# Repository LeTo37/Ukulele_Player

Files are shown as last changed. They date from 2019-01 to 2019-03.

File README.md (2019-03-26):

# Human-Robot Ukulele Player (H-RUP)
Designing and building a Human-Interactable Robotic Ukulele player. Below is a link to video of me playing the H-RUP!

Sawyer Ukulele Tune (https://www.youtube-nocookie.com/embed/SKRP2N837I4 "HRUP")

## Introduction
This repository holds all of the relevant documentation, including mechanical designs, circuit designs, code and data-sheets of the parts used in the process of designing and building the Human-Robot Ukulele Player (H-RUP). 

This project was done in fulfillment of the requirements of a winter quarter project for the completion of my Master of Science in Robotics at Northwestern University.

## Approach

The basic approach I followed was to develop a 4x4 bank of solenoids to be housed above a small section of the ukkulele neck, placed above a part of the ukulele whereby this bank of solenoids will be able to press a pretty comprehensive combination of notes/chords, enough to be able to play most, if not all songs.

These solenoids are controlled using a PIC32MX795F512H microcontroller and a driver circuit. The Ukulele and Solenoid housing were designed and constructed by 3D printing and Laser Cutting. Coding was done C and Python.

## Directories

### Mechanical Designs

This directory holds the mechanical designs used to construct the H-RUP. Designs were done in Onshape, an open source, online CAD tool.

### Circuit Schematics

This directory holds the circuit design schematics for the solenoid drivers. Designs wer done in kiCad, an open source, PCB and schematics design tool.

### Docs
This directory holds the datasheets for all the relevant components used and any other useful documentation.

### Code
This directory holds the code used to program the PIC32MX795F512H microcontroller on the [NU32](http://hades.mech.northwestern.edu/index.php/NU32) breakout board. It also holds the user code used to run and interact with the H-RUP

## Using the H-RUP
[Ukulele Jukebox](Code/user_code/Ukulele_Jukebox.py) is a Python executable that will initiate the user interface for the H-RUP. First the user will be welcomed and prompted for a choice of entering their own song or choosing from a list of preset songs on the Jukebox.

If a user wants to create their own song, they will be asked for each individual chord and the amount of milliseconds they wish for that chord to be played. The user can end a song by entering a '%' when asked for a chord.

If a user wants to choose a song, they will be given a list of songs from which to choose.

In both cases, once a song has either been written or chosen, the list of chords and milliseconds will be sent to the microcontroller. At this point the strum light will count down from 3 with 3 long flashes. It will then flash quickly each time a chord is played to indicate that a strumming sequence should begin!

Happy Strumming!

<p align="center">
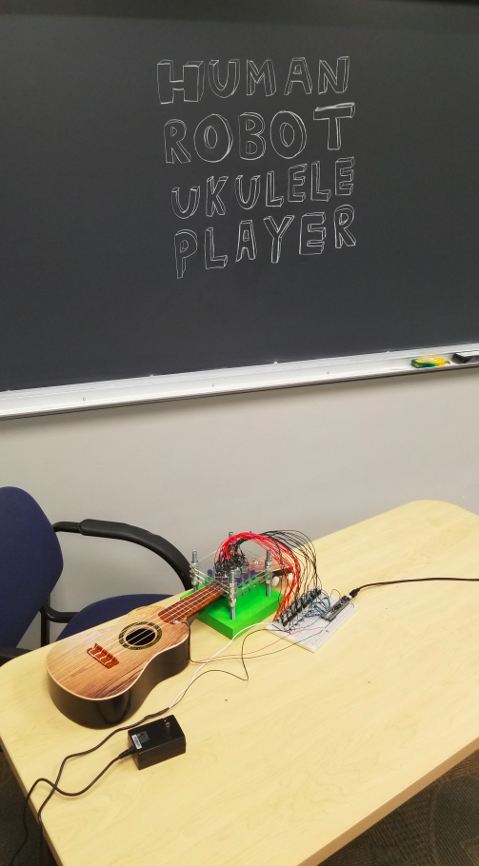
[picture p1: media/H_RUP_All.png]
  
</p>

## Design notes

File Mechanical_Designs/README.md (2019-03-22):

# Mechanical Designs

## Final Full Assembly

This final design was implemented with a combination of 3d printing PLA parts and Laser cutting Acryllic parts. The Full Assembly can be found [here](Full_Assembly.stl). The fully constructed mechanism is shown in the image below:
<p align="center">
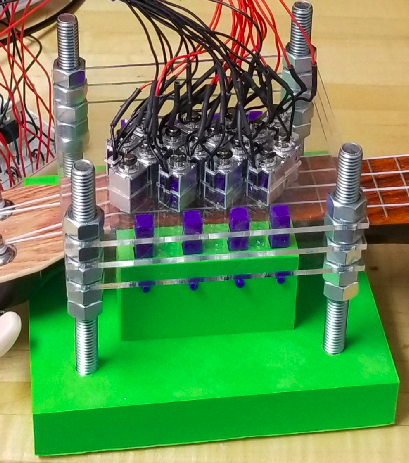
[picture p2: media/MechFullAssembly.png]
  
</p>
As can be seen, it is comprised of a few different components which are described below.

## 3D Printables

The design of the [Base and Ukulele Housing](3D_Prints/Base_and_Uke_Housing.stl) was 3d printed out of PLA plastic. This serves as the base of the design and is where the neck of the Ukulele rests. It is made out of a [base](3D_Prints/base.stl) and a [housing](3D_Prints/Housing_Base.stl) for the Ukulele. It was designed such that the Ukulele can rest with it's first four frets accessable to the solenoids. This is a big chunk of plastic and was designed as such, so as to provide overall stability to the system.

Further parts that were 3D printed include the [Housing Aligners](3D_Prints/Housing_Aligners.stl), the [Pins](3D_Prints/Pin.stl) and the [Fingertips](3D_Prints/Fingertips.stl). The Housing Aligners are used to connect the 3D printed Base and Ukulele Housing to the laser cut parts that house the solenoids described below. This is done as a way of ensuring the parts line up such that the solenoids are above the correct part of the Ukulele neck. The Pins are used simply to connect the Housing Aligners to the Base and Ukulele Housing to improve stability.

The Fingertips were printed out of NinjaFlex 3D printer filament. This was done as it produces a much more flexibale part. These fingertips were connected to the end of the solenoid plunger, as an end-effector to press chords on the Ukulele.

## Laser Cuttables

In order to both house and align the solenoids such that they are able to press the correct chords, the solution was designed to be done in three layers. This decision was made in order to allow for as much air flow through the system as possible - necessary since the solenoids are being driven over voltage. Each layer was drawn and saved in '.svg' format, these drawings were then cut out of Acryllic using a laser cutter.

As such, the [bottom layer](Laser_Cuts/bottom_solenoid_holder.svg) was drawn to have holes for the solenoid plunger to be able to press down on the correct part of the Ukulele neck, but these holes are only big enough for the plunger, that is to say, this layer holds the solenoids from the bottom. It also includes square holes for the 3D printed Housing Aligners to fit through, so as to ensure accurate alignment. The [middle layer](Laser_Cuts/middle_solenoid_holder.svg) was drawn to house the solenoids and ensure their alignment is such that their plungers go through the holes on the bottom layer. Lastly, the [top layer](Laser_Cuts/top_solenoid_holder.svg), similarly to the bottom layer, has holes large enough only for the solenoid plungers and secondary holes for the solenoid wiring. This layer serves to compress the solenoids so that when they are activated, all of their force goes into pressing the plunger down onto the Ukulele.

## Other Parts
The [Solenoid](Other_Parts/Solenoid.stl) and [Ukulele Neck](Other_Parts/Ukulele.stl) designs were used within the CAD design of all of the necessary parts that make the final full assembly. They were made to be the same size as the real part such that the designed parts were accurate and reliable.

Threadbars and appropriately sized nuts were ordered from McMaster-Carr to be used in the real life assembly of the design. In CAD, this [Threadbar](Other_Parts/Threadbar.stl) was used as a placeholder for the final full assembly design. The parts ordered and used were:
* Low-Strength Steel Hex Nut, Grade 2, Zinc-Plated, 3/8"-16 Thread Size
* Low-Strength Zinc-Plated Steel Hex Head Screw, 3/8"-16 Thread Size, 5" Long, Fully Threaded

The threadbar and nut combination was used to both compress and space the three laser cut-out layers that house the solenoids.

## Unused Designs
This folder holds some of the unused designs that were iterated through in the process of getting to the final design shown in the root of this directory.

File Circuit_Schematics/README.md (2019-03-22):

# Circuit Schematics

The schematics in this directory called [Solenoid Drivers 1](Solenoid_Drivers_1.png) and [2](Solenoid_Drivers_2.png) are mostly the same. Between the two of them they describe 16 solenoid driver circuits designed to allow Digital I/O pins on the PIC32 microcontroller to activate and deactivate the solenoids with logic highs and lows. The only differnece between Solenoid Drivers 1 and 2 are the Digital I/O pins to which the solenoid driver circuit is connected.

The basic circuit that is repeated for all 16 solenoids consists of the Digital I/O pin going through a 1 kilo Ohm resistor to the base of an NPN Darlington transistor. The collector of which is connected to a 7.5V power supply (32W, 4.32A AC/DC wall adapter) through a parallel combination of the solenoid being activated and a flyback diode. The emmitter of the transistor is connected to ground. The datasheets for the components used can be found [here](../Docs)

The [LED](LED.png) schematic shows a simple connection from the PIC32 Digital I/O to an LED with a 330 Ohm pulldown resistor. This LED is used as the Start and Strum Light to indicate to the user when to strum.

These schematics were developed using KiCad, as such, the KiCad '.sch' files are included as well as screenshots of the schematics for easier viewing.

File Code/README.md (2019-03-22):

# Code

This repository holds all of the code necessary to use the H-RUP. 

## Microcontroller Code
This directory holds the code used to program the PIC32MX795F512H microcontroller. The purpose of this code is to read a song sent into the microcontroller by the user code and convert that into digital highs or lows such that the solenoids actuate at the correct time. This allows the H-RUP to press chords on the Ukulele in the correct sequence and timing, producing a song.

The PIC32MX795F512H code is all done in C for use with the NU32 breakout board.

## User Code
This directory holds code that defines how the user interacts with H-RUP. Included in this directory is a Python script called [Ukulele Jukebox](/Ukulele_Jukebox.py) as well as text files holding the chords and timing instructions for a few preset songs.

The protocol Ukelele Jukebox uses for reading songs is defined as `chord,milliseconds,chord,milliseconds,..`. That is to say the code reads a chord and then the amount of milliseconds that chords should be played for seperated by a comma. The list of chords and milliseconds ends when there are no more commas.

Ukulele Jukebox is an executable that will initiate the user interface for the H-RUP. First the user will be welcomed and prompted for a choice of entering their own song or choosing from a list of preset songs on the Jukebox.

If a user wants to create their own song, they will be asked for each individual chord and the amount of milliseconds they wish for that chord to be played. The user can end a song by entering a '%' when asked for a chord.

If a user wants to choose a song, they will be given a list of songs from which to choose.

In both cases, once a song has either been written or chosen, the list of chords and milliseconds will be sent to the microcontroller. At this point the strum light will count down from 3 with 3 long flashes. It will then flash quickly each time a chord is played to indicate that a strumming sequence should begin!

## NU32
All of the code found in both the [micro code](/micro_code) directory and the [NU32 Utility](/NU32_Utility) that has "NU32" in its name is code developed by the makers of the [NU32](http://hades.mech.northwestern.edu/index.php/NU32) breakout board for the PIC32MX795F512H microcontroller. This code includes Utility code (in the NU32 Utility directory) which defines functions and data types for the bootloader. This bootloader is included in the micro code directory along with an NU32 library of functions that are useful for initialising the micro as well as serial communication to and from the micro.

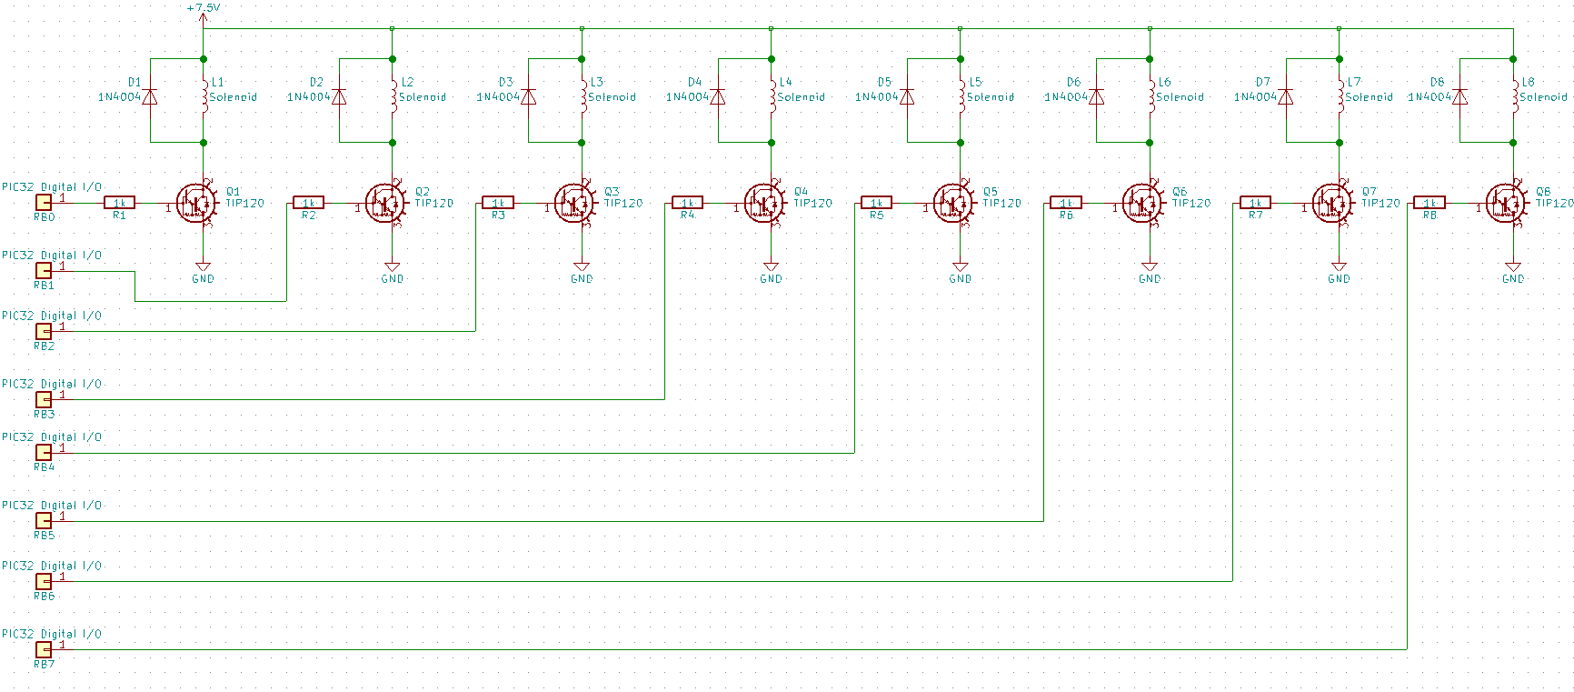
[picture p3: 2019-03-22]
Circuit_Schematics/Solenoid_Drivers_1.png

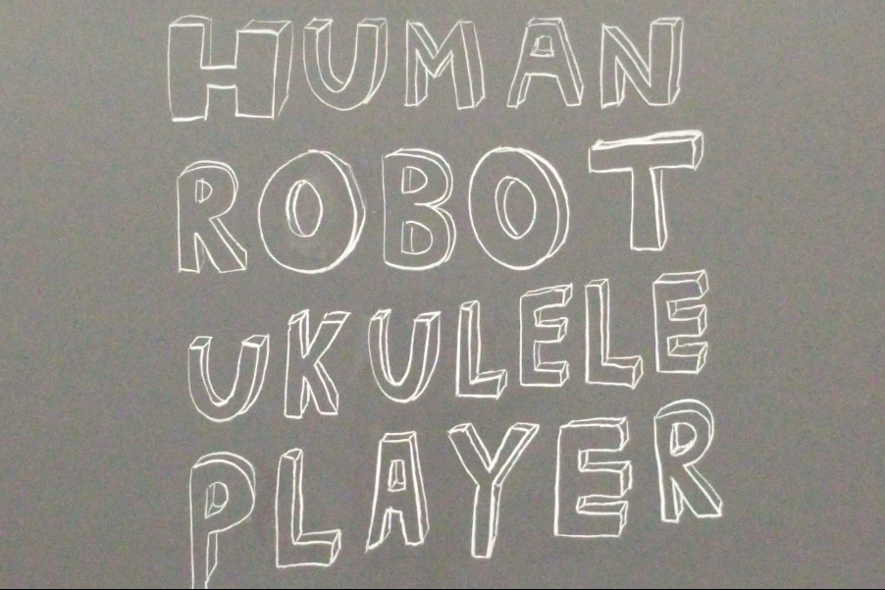
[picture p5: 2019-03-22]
media/H_RUP_Writing.png

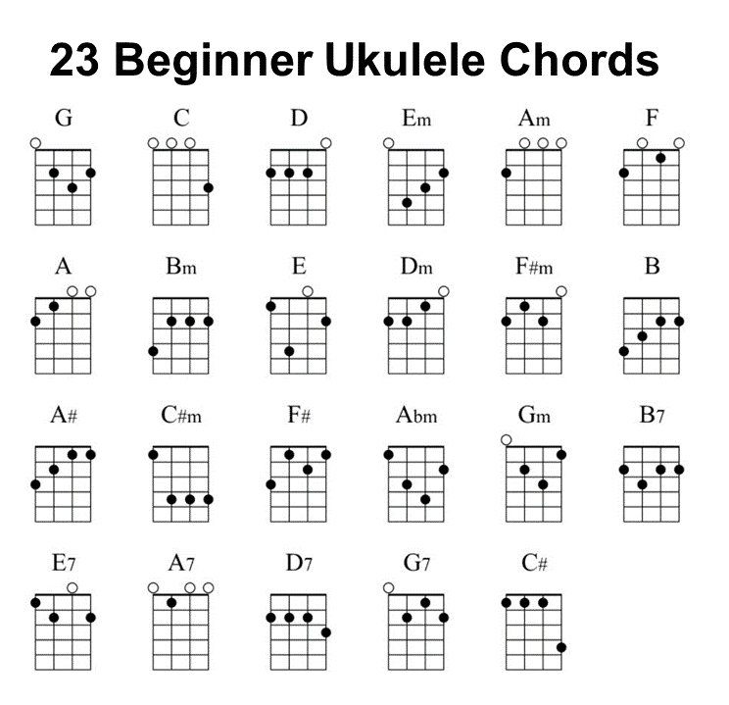
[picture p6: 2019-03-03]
Docs/Base23_Ukulele_Chords.png

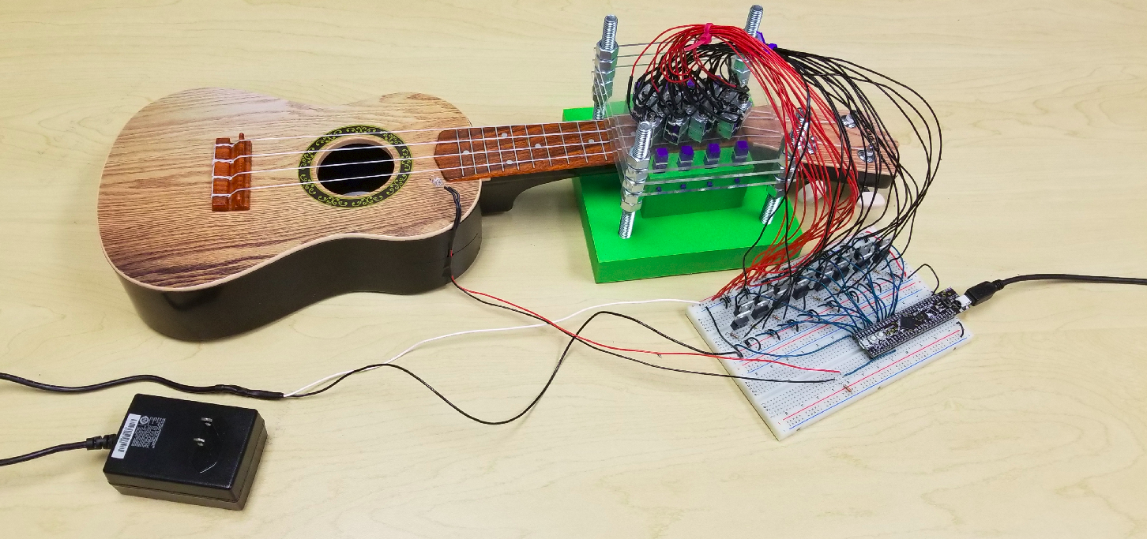
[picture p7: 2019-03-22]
media/H_RUP.png

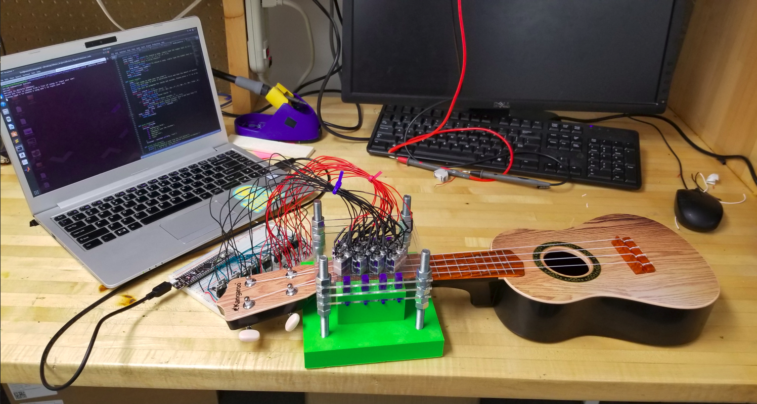
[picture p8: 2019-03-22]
media/H_RUP_Code.png

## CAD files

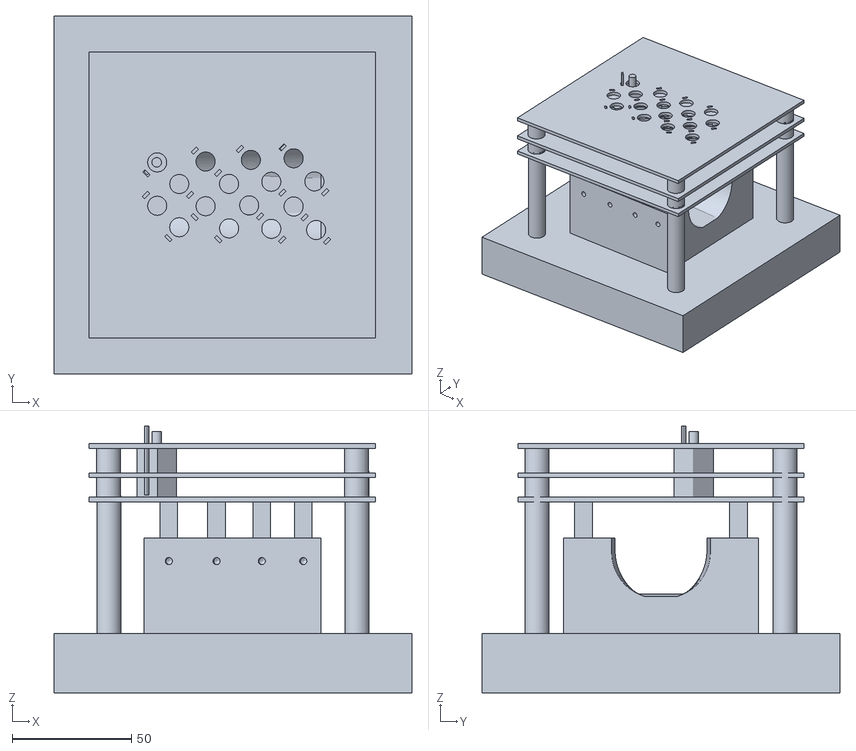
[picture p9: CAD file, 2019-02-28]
Mechanical_Designs/Full_Assembly.stl
150.0 x 150.0 x 111.8

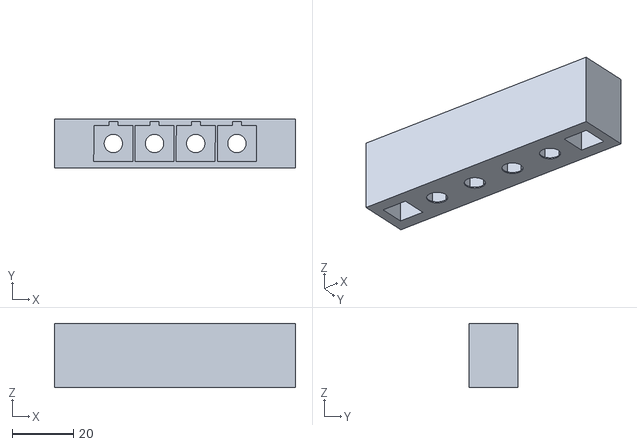
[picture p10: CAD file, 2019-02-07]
Mechanical Designs/Housing_Solenoids_2.stl
79.0 x 16.0 x 21.0

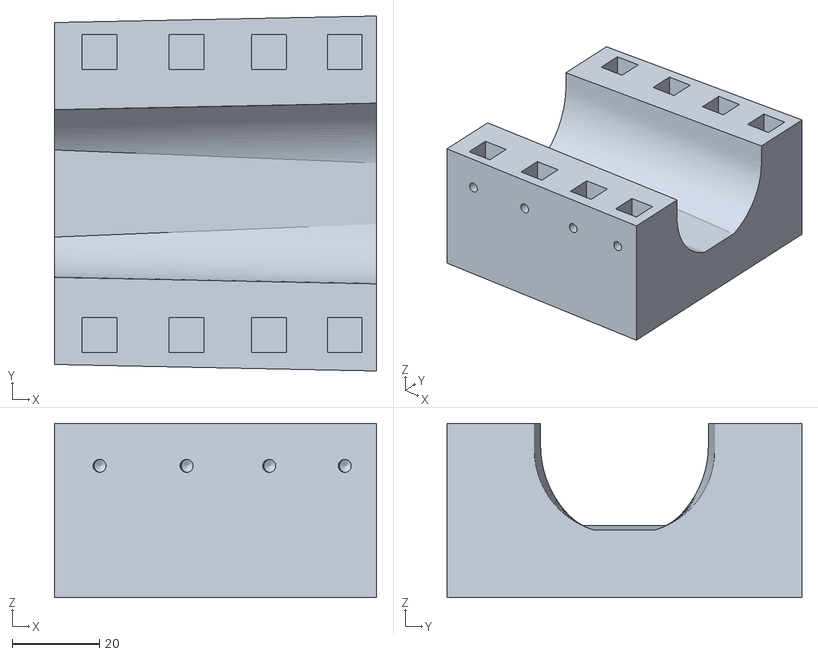
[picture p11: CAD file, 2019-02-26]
Mechanical_Designs/3D_Prints/Housing_Base.stl
74.0 x 81.5 x 40.0

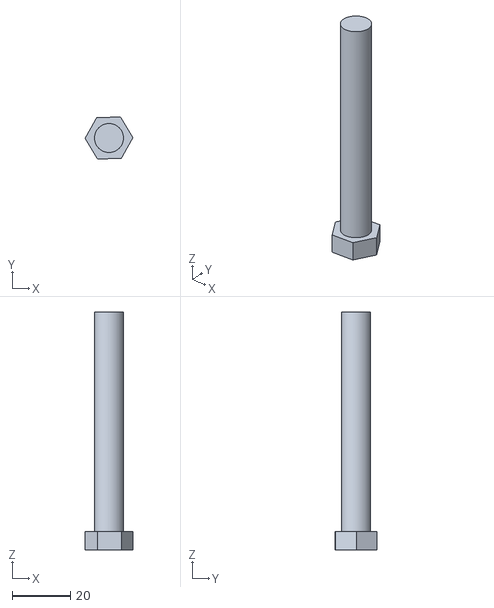
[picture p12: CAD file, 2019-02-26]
Mechanical_Designs/Other_Parts/Threadbar.stl
16.5 x 14.4 x 82.0

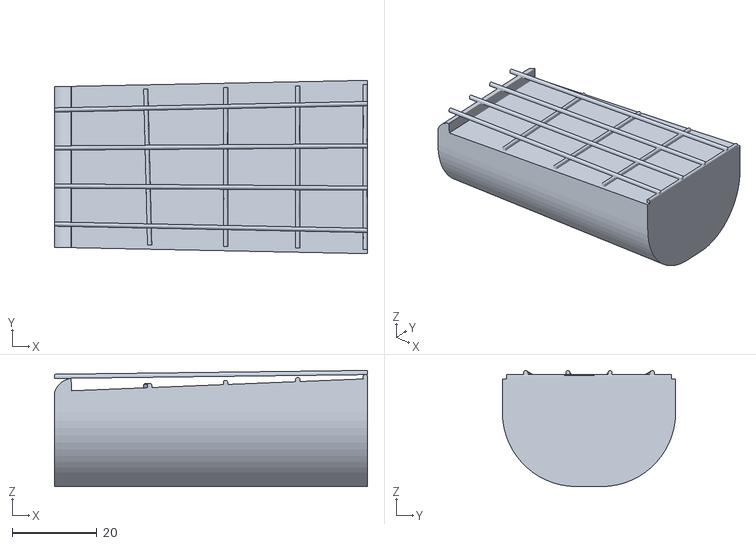
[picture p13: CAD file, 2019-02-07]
Mechanical Designs/Uku_Neck.stl
74.0 x 41.0 x 27.5

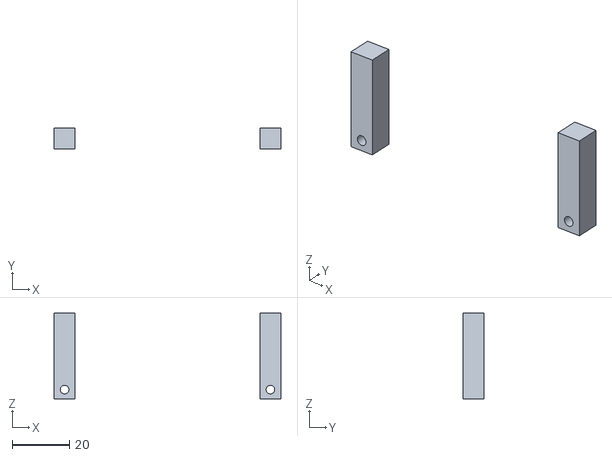
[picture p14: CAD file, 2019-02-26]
Mechanical_Designs/3D_Prints/Housing_Aligners.stl
79.4 x 7.40 x 30.0

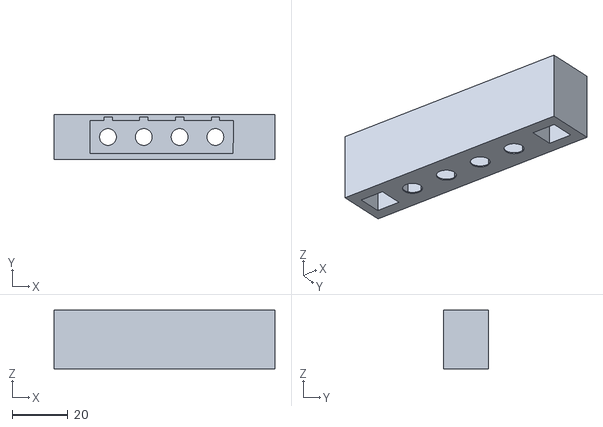
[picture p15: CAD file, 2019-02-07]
Mechanical Designs/Housing_Solenoids_1.stl
79.0 x 16.0 x 21.0

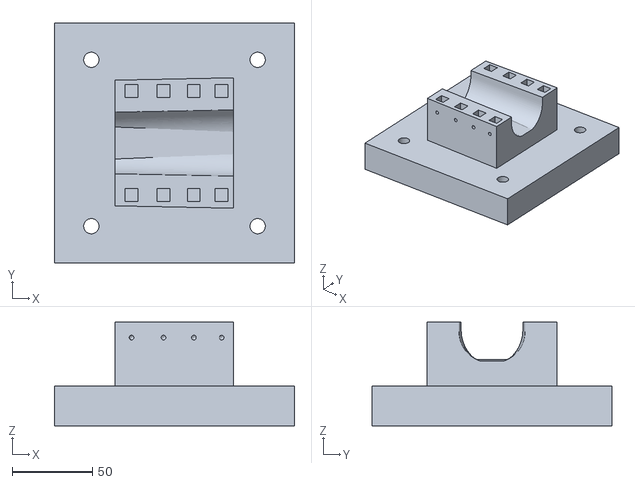
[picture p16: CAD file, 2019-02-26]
Mechanical_Designs/3D_Prints/Base_and_Uke_Housing.stl
150.0 x 150.0 x 65.0

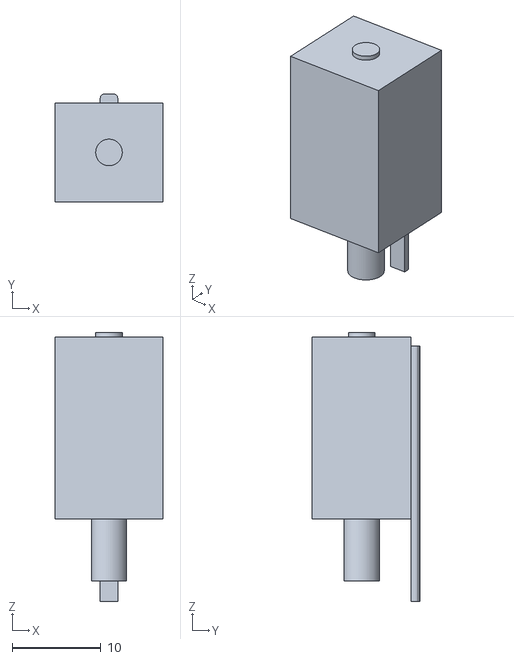
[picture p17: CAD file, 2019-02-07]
Mechanical_Designs/Other_Parts/Solenoid.stl
12.2 x 12.2 x 30.3

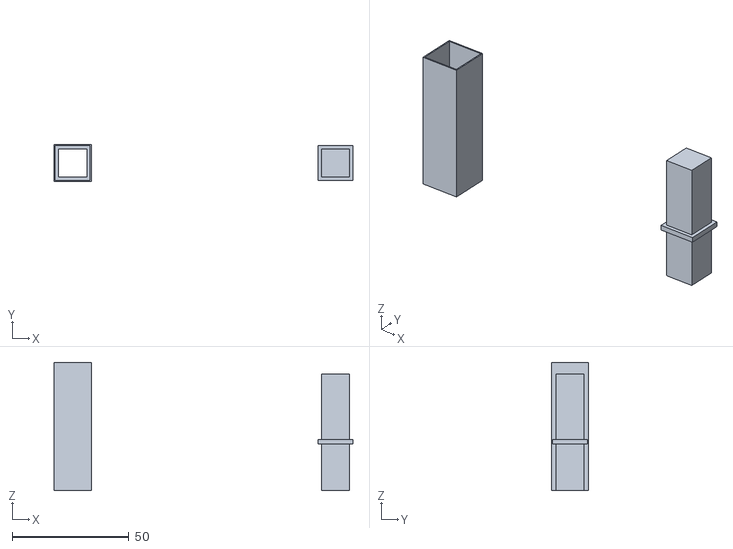
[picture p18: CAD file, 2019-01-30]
Mechanical Designs/Finger_Vol2.stl
128.2 x 16.0 x 55.0

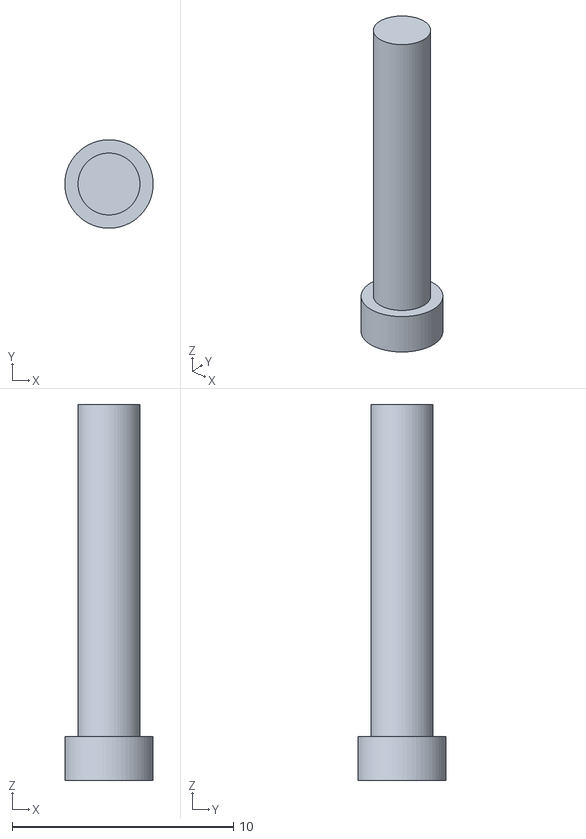
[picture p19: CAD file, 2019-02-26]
Mechanical_Designs/3D_Prints/Pin.stl
4.00 x 3.99 x 17.0

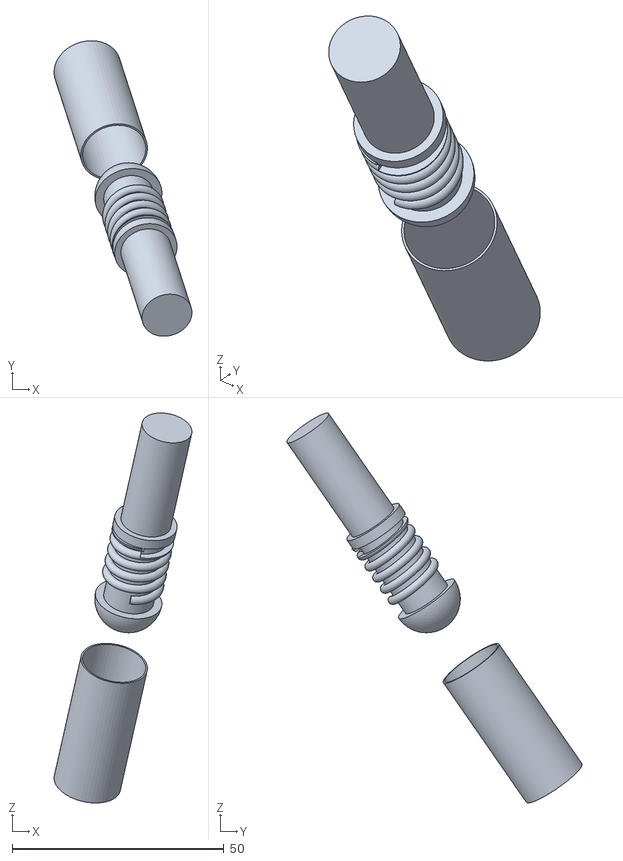
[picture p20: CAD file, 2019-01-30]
Mechanical Designs/Finger_Vol1.stl
32.6 x 69.8 x 92.1

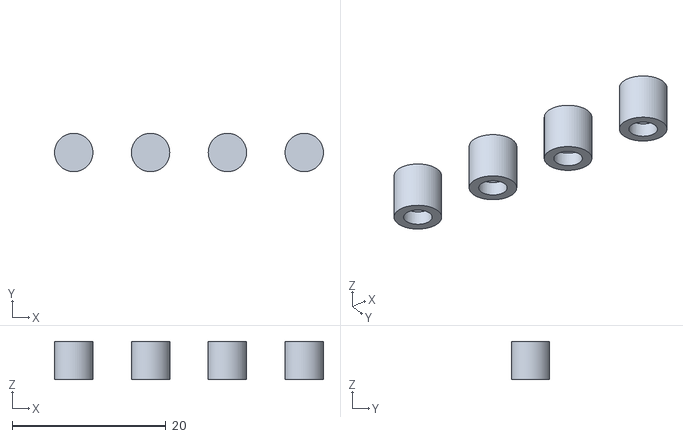
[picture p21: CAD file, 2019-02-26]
Mechanical_Designs/3D_Prints/Fingertips.stl
35.0 x 4.99 x 5.00

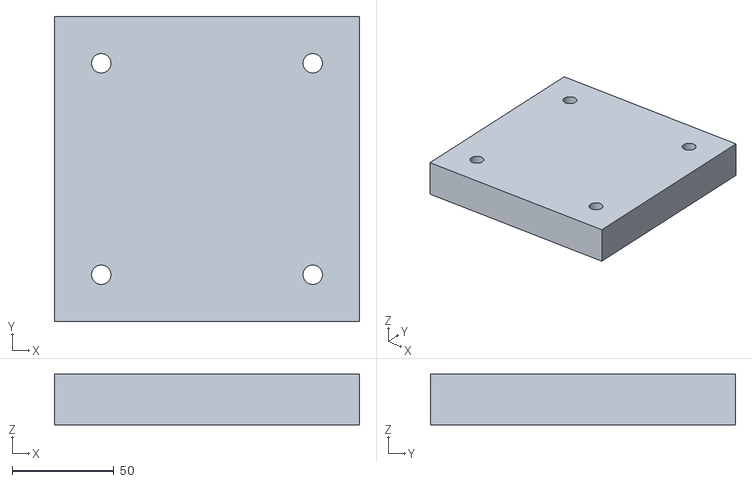
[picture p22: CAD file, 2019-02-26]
Mechanical_Designs/3D_Prints/base.stl
150.0 x 150.0 x 25.0

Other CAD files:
Mechanical_Designs/Other_Parts/Ukulele.stl
Mechanical_Designs/Unused_Designs/Full_Assembly.stl
Mechanical_Designs/Unused_Designs/Housing_Base.stl
Mechanical_Designs/Unused_Designs/Housing_Connectors.stl

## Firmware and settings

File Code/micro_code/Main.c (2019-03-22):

#include "chords.h"  
#include <string.h>
#include <stdio.h>

#define SONG_LENGTH 10000

int main(void) {
  int chord_counter = 0;
  char chords[10000][4];
  char char_secs[10000][4];
  int seconds[10000];
  int i = 0;
  char debugprint[100];
  char song[SONG_LENGTH];

  const char* split = ",";
  char* token;
  unsigned int ch_or_sec = 0; //bool type int to flag whether input is chord or seconds.

  NU32_Startup(); // cache on, min flash wait, interrupts on, LED/button init, UART init
  //DIO setup:
  TRISB = 0x0000;         // set B0-B15 as digital outputs
  TRISDbits.TRISD10 = 0;  //set D10 as digital output (strum light)
  LATDbits.LATD10 = 0;    //light off to start
  NU32_WriteUART3("Let's Go!\r\n");
  while(1)
  {
    LATB = 0x0000;
    NU32_ReadUART3(song, SONG_LENGTH);
    // NU32_WriteUART3("Playing song:\r\n");
    
    token = strtok(song,split);
    while (token != NULL)
    {
    	if (ch_or_sec == 0)
    	{
	    	strcpy(chords[chord_counter],token);
	    	ch_or_sec = 1;
        // sprintf(debugprint,"HosJy: %s \r\n",chords[chord_counter]);
        // NU32_WriteUART3(debugprint);
	    }
	    else if (ch_or_sec == 1)
    	{
	    	strcpy(char_secs[chord_counter],token);
        seconds[chord_counter] = ((int)char_secs[chord_counter][0]-48)*1000;
        seconds[chord_counter] += ((int)char_secs[chord_counter][1]-48)*100;
        seconds[chord_counter] += ((int)char_secs[chord_counter][2]-48)*10;
        seconds[chord_counter] += ((int)char_secs[chord_counter][3]-48);

        sprintf(debugprint,"seconds: %d \r\n",seconds[chord_counter]);
        NU32_WriteUART3(debugprint);
	    	chord_counter++;
	    	ch_or_sec = 0;
	    }

	   	token = strtok(NULL, ",");
    }

    starter_light();

     for(i=0; i < chord_counter; i++ )
     {
      strum_light();
     	play_chord(chords[i], seconds[i]);
      //debugging
      sprintf(debugprint,"Chord: %s \r\n",chords[i]);
      NU32_WriteUART3(debugprint);
      sprintf(debugprint,"seconds: %d \r\n",seconds[i]);
      NU32_WriteUART3(debugprint);
     }
     if (i == chord_counter && i != 0)
     {
       chord_counter = 0;
       NU32_LED1 = !NU32_LED1;
       LATDbits.LATD10 = 0;    //light off to end
       NU32_WriteUART3("Done!\r\n");
     }

  }

  return 0;
}

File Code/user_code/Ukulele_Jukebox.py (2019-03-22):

#!/usr/bin/env python
import serial
# import time

ser = serial.Serial('/dev/ttyUSB0')
ser.baudrate = 230400
ser.timeout = 10.0
if ser.name:
	print("Serial Connection Success")

def main():
	print("Hello!\nWelcome to Ukulele Jukebox!")
	print("Would you like to choose from a list of songs or input your own?")
	while (1):
		ans = raw_input("Please type c to choose a song and i to input your own\n")
		if (ans == 'c'):
			list_songs()
		elif (ans == 'i'):
			input_song()
		else:
			print("Please enter a valid choice")

def list_songs():
	global filename
	print_list_songs()
	song_number = 100
	song_number = raw_input("To choose a song, simply type the number next to it\n")
	while song_number not in {'1','2','3','4','5','6'}:
		print("Please enter a valid choice")
		print_list_songs()
		song_number = raw_input("To choose a song, simply type the number next to it\n")
	pick_song(int(song_number))
	f = open (filename,"r")
	song = f.read() + "\r\n"
	send_song(song)

def input_song():
	song = ""
	print("Get ready to make your own song!")
	print("You will need to enter a chord/note first and then the amount of seconds it needs to be played for")
	print_list_chords()
	print("You will be prompted for chords and seconds. Please enter a '%' as a chord when you are finished!")
	chord =""
	while not (chord == '%'):
		chord = raw_input("Enter Chord: ")
		while chord not in {'G','C','D','Em','Am','F','A','Bm','E','Dm','Fshm','B','Ash','Cshm','Fsh','Abm','Gm','B7','E7','A7','D7','G7','Csh','Am7','Em7','%'}:
			print_list_chords()
			chord = raw_input("Enter Chord: ")
		if not (chord == '%'):
			seconds = raw_input("Enter milliseconds: ")
			while (seconds > 7000 or seconds < 1000):
				print("Please enter milliseconds greater than 999 and less than 7001 ms")
				seconds = raw_input("Enter milliseconds: ")
			song = song + chord +","+ seconds + ","
	song = song[:-1]
	if len(song) > 3:
		send_song(song)



def pick_song(arg):
	global filename
	switcher = {
		1: "Redemption_Song",
		2: "Let_it_be",
		3: "Somewhere_over_the_rainbow",
		4: "Riptide",
		5: "Rising_Sun",
		6: "test"
	}
	filename = switcher.get(arg, "test")

def print_list_songs():
	print("Please choose a song from the list below!")
	print("1 -> Redemption Song, Bob Marley (Difficult Strumming)\n"
		+ "2 -> Let it be, The Beatles\n"
		+"3 -> Somewhere over the Rainbow, Israel Kamakawiwo'ole\n"
		+"4 -> Riptide, Vance Joy\n"
		+"5 -> House of the Rising Sun, The Animals\n")

def print_list_chords():
	print("Please pick from the following list of chords only:")
	print("G -> G\n"
		+"C -> C\n"
		+"D -> D\n"
		+"Em -> E minor\n"
		+"A -> A minor\n"
		+"F -> F\n"
		+"A -> A\n"
		+"Bm -> B minor\n"
		+"E -> E\n"
		+"Dm -> D minor\n"
		+"Fshm -> F sharp minor\n"
		+"B -> B\n"
		+"Ash -> A sharp minor\n"
		+"Cshm -> C sharp minor\n"
		+"Fsh -> F sharp\n"
		+"Abm -> A flat minor\n"
		+"G -> G minor\n"
		+"B7 -> B dominant 7\n"
		+"E7 -> E dominant 7\n"
		+"A7 -> A dominant 7\n"
		+"D7 -> D dominant 7\n"
		+"G7 -> G dominant 7\n"
		+"Csh -> C sharp\n"
		+"Am7 -> A dominant 7 minor\n"
		+"Em7 -> E dominant 7 minor\n"
		)

def send_song(song):
	print(song)
	ser.write(song)
	while ser.read() != '!':
		# print(ser.read(10)) # Check out how to do this for reals
		pass;
	ser.flush();

if __name__ == '__main__':
   	try:
   		main()
   	except KeyboardInterrupt:
   		print("script killed")
   		ser.close()

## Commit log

2019-01-30 Added mechanical designs and edited README
    [Finger_Vol1.stl, Finger_Vol2.stl, Housing.stl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]
2019-01-31 Added schematics for solenoid drivers. Added data sheets for proposed components.
    [Solenoid_Drivers_1.sch, Solenoid_Drivers_2.sch]
2019-02-07 New refined iteration of mechanical designs
    [Fingertips.stl, Full_Assembly.stl, Housing.stl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]
2019-02-26 New and Improved Design - For combo of 3d Printer and Laser Cutter
    [Base_and_Uke_Housing.stl, Finger_Vol1.stl, Finger_Vol2.stl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]
2019-02-26 Full Assembly Added
    [Full_Assembly.stl]
2019-02-28 Drawings (svgs) added, Seperate READMEs
    [Full_Assembly.stl, bottom_solenoid_holder.stl, middle_solenoid_holder.stl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]
2019-02-28 Reformat and README
    [Base_and_Uke_Housing.stl, Fingertips.stl, Housing_Aligners.stl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]
2019-02-28 fixed README links
    [Base_and_Uke_Housing.stl, Finger_Vol1.stl, Finger_Vol2.stl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]
2019-03-13 timing now in milliseconds
2019-03-20 timing now in milliseconds and strum light added
2019-03-20 Docs for power supply
2019-03-22 Schematics directory updated
    [LED.sch, Solenoid_Drivers_1.sch, Solenoid_Drivers_2.sch]
2019-03-22 General Restructure
    [Base_and_Uke_Housing.stl, Finger_Vol1.stl, Finger_Vol2.stl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]
